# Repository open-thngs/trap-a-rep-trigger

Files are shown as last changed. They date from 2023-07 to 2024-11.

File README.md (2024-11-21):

# Openthing 2 - RepTrap 

The RepTrap is a "motion detector" and camera trigger designed to detect small and/or cold-blooded animals such as frogs, lizards, birds, and other wildlife. It doesn't detect motion directly but instead identifies changes in height within the range of its four Time-of-Flight (ToF) sensors. Any height change within this range triggers a connected camera's shutter.

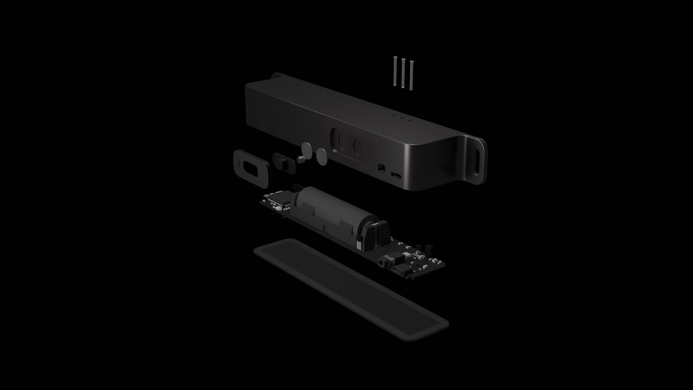
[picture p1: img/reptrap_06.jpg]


## BLE 

The device and software is Bluetooth ready but it is currently missing an App. Here are commands which can be send to configure and change the device:

- Bluetooth Service [`0x7017`]
    - **Status** Characteristic [`0x701C`]
      **Description**: Refelcts the current device status as a string
      **Values**: `running` `calibrating`
    - **Command** Characteristic [`0x7018`]
      **Description**: Accepts specific device commands
      **Values:**
      - `stop`: Stops the BLE Service on the device
      - `calibrate`: Triggers a re-calibration of the device
      - `xtalk`: Triggers an cross-talk and offset calibration of the device (only needed for manufacturing, should not be used)
      - `trigger`: Triggers the camera shutter and focus signal
    - **Config** Characteristic [`701D`]
      **Description**: Using this characteristic you can configure the device (**experimental**). You can send a 3 Byte payload consisting of the type (first byte) and tzhe data(second and third byte). Example `[0xA0, 0x00, 0x00]` Type 0xA0 Signal Threashold with value 0
      **Values**:
        - `0xA0` - Signal Threshold
        - `0xA1` - Sigma Threshold
        - `0xA2` - Time to Measure
        - `0xA3` - Measure Interval

**Note:** The config characteristic is experimental. The limits of the values might not be checked or some value combination might lead to an unresponsive sensor. A re-flash of the firmware might be needed to fix the device. You can read the datasheet of the ToF Sensor to get the details of this values.

**Note:** If you want to power the device permanently via USB-C the BLE Service will be started once you boot the device with USB-C connected. You can send teh command to stop the BLE Service to save energy. 

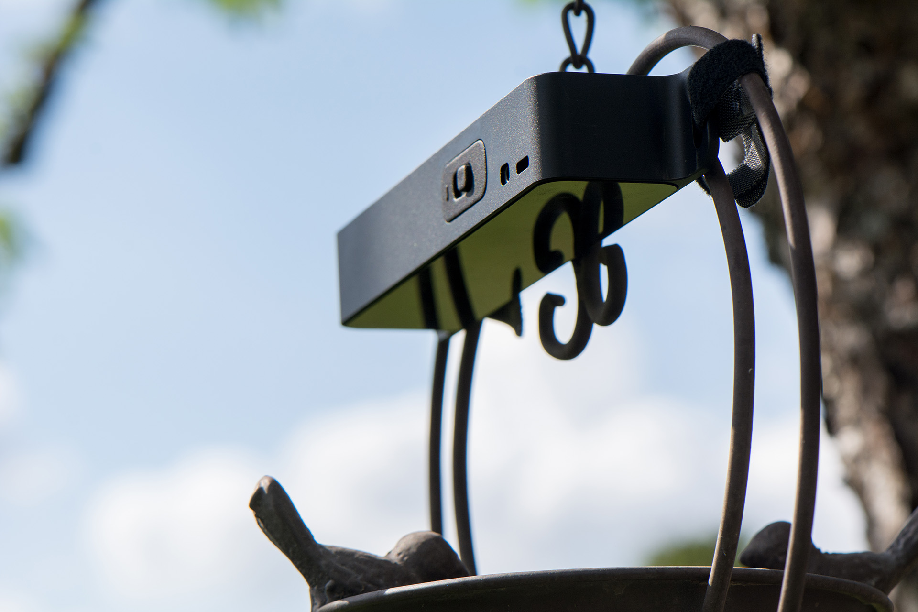
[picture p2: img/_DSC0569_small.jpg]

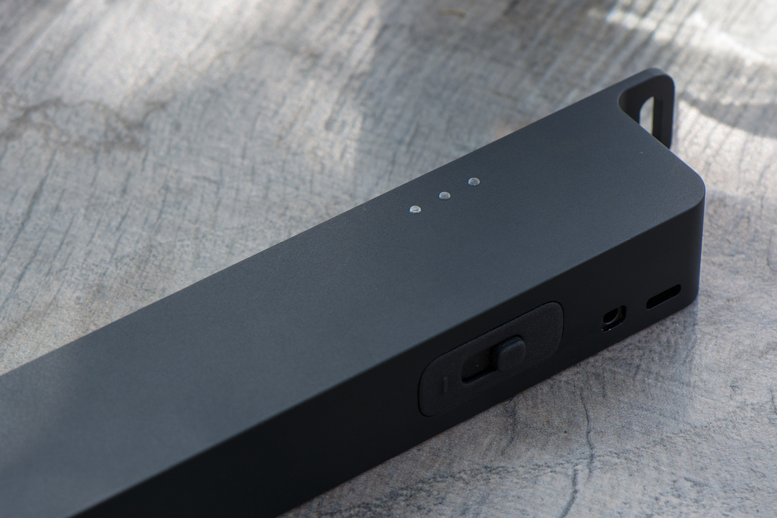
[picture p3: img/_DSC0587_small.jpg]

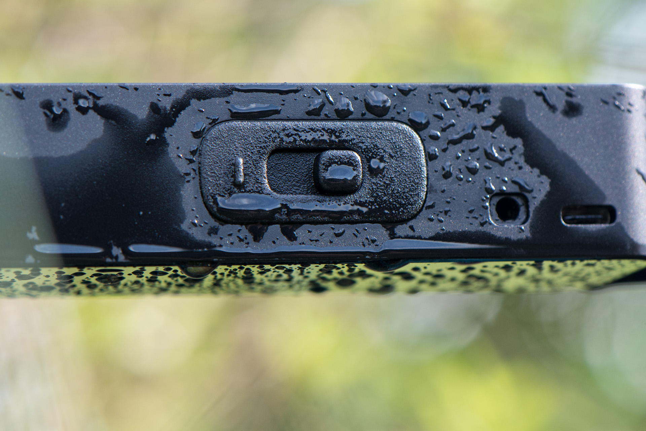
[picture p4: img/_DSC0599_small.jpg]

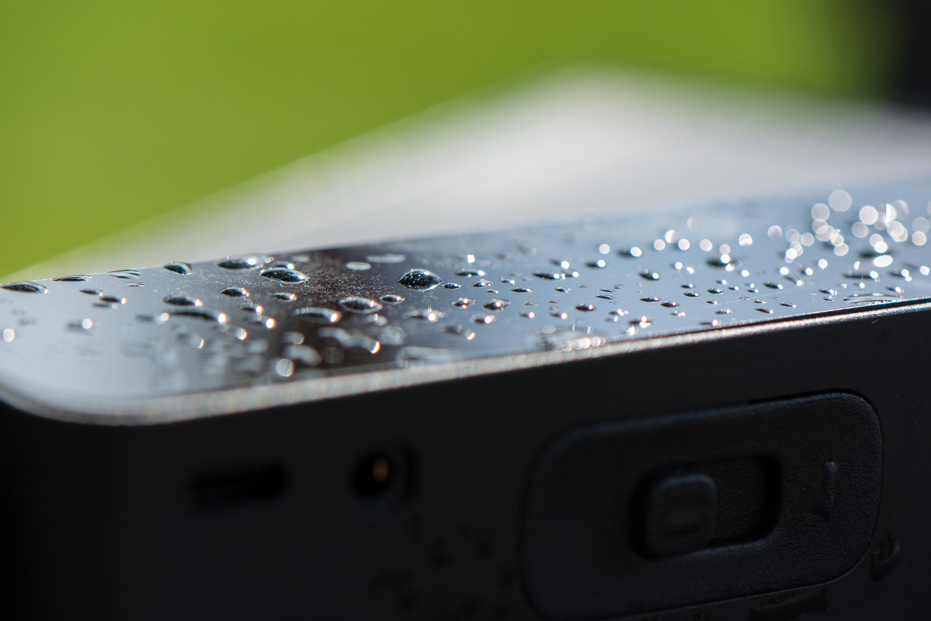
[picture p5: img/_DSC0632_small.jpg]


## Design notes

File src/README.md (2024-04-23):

## Toit usage
flash: `jag flash -p COM19 --chip esp32s3`
install container: `jag container install app -D jag.disabled -D jag.timeout=5m src/main.toit`

## Full Firmware build
compile main app `toit.compile -w komodo.snapshot src/komodo.toit`
install container to envelope: `firmware -e firmware-esp32s3.envelope  container install komodo komodo.snapshot`
flash: `firmware -e firmware-esp32s3.envelope flash -p COM19 --baud 921600 --chip esp32s3`

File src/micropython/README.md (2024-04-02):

If the Sensor is used for the first time it might need calibration (if a cover glas is used)
Make sure to set the Sensor on a 10cm height and place a white paper below it and run 
```
import calibrator
calibrator.calibrate()
```

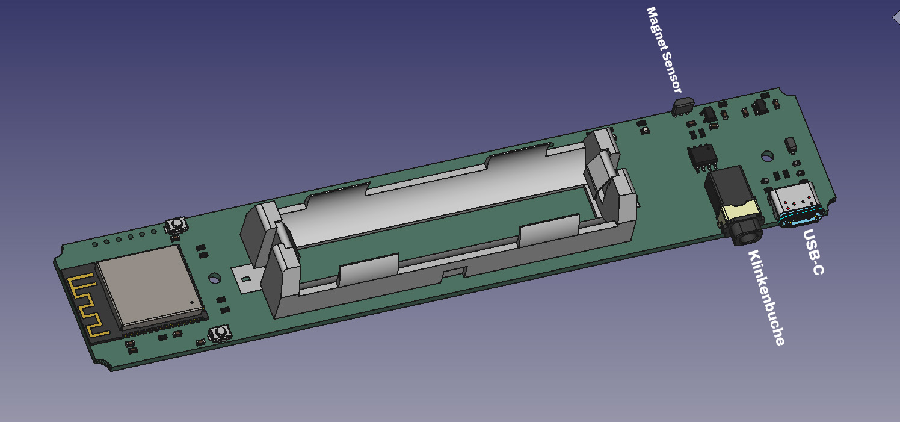
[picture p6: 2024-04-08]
img/3ddescription.jpg

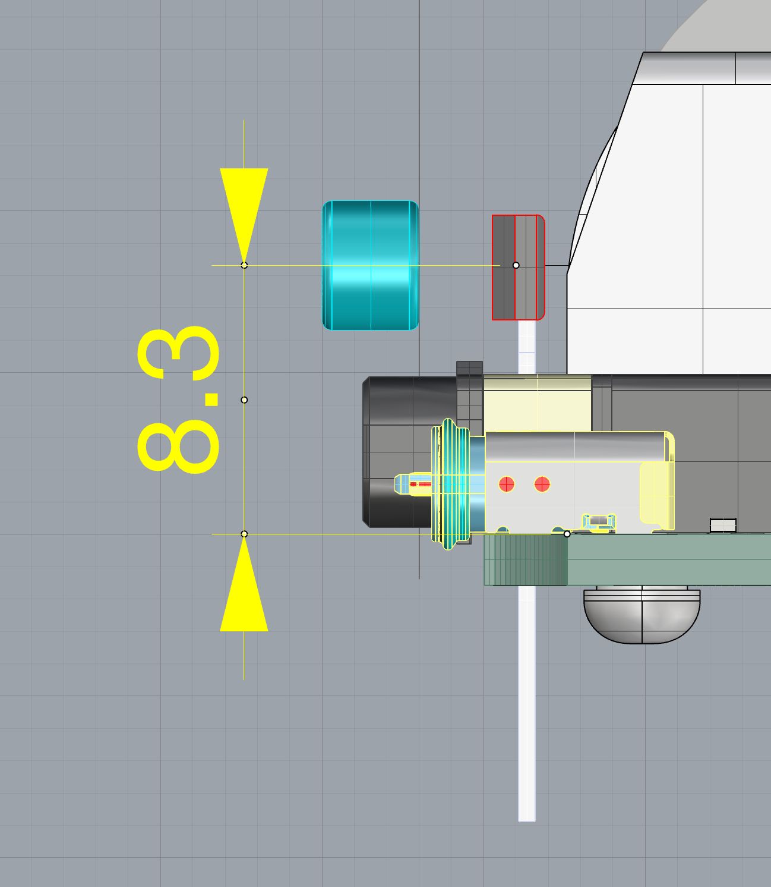
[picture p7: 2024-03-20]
housing/magnet-sensor-height.jpg

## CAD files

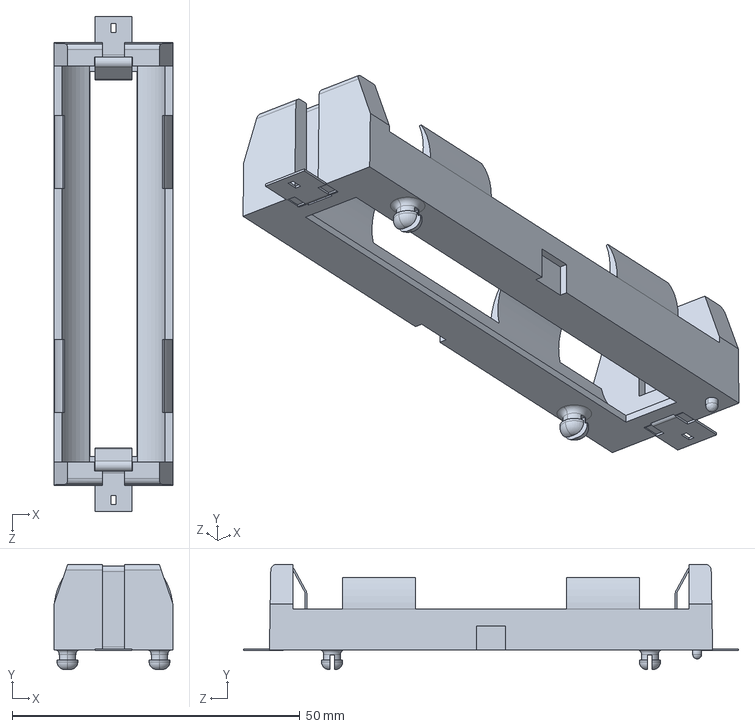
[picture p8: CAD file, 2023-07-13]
pcb/components/1042P/1042P.stp
20.7 x 18.3 x 86.1 mm

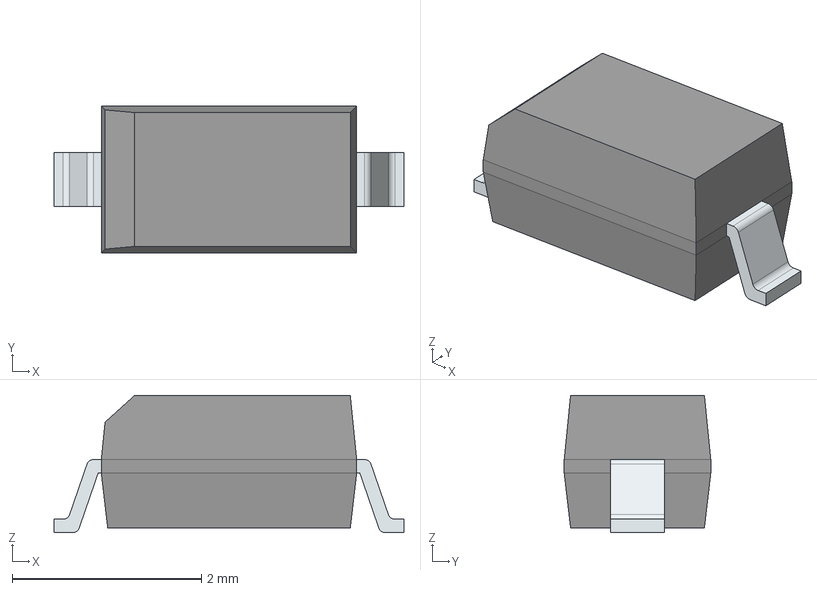
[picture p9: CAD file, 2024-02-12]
pcb/components/1N5819HW-7-F/3D/1N5819HW-7-F.stp
3.70 x 1.55 x 1.45 mm
FilletPinL
FilletPinR

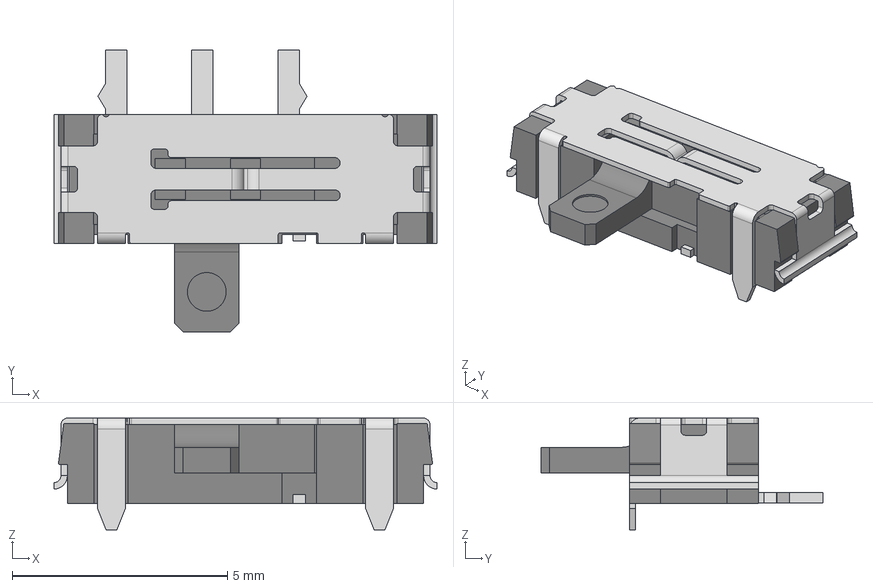
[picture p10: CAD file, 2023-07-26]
pcb/components/450405020524/STP_450405020524 (rev1).stp
8.90 x 6.55 x 2.60 mm
Frame
Cover
Pin 2
Pin 4
Slider 1
Pin 1
Pin 3
Slider
Pin 5

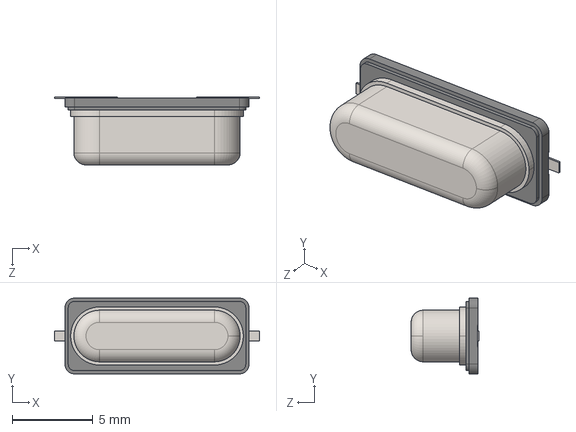
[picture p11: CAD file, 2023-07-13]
pcb/components/ABLS-12.000MHZ-B4-T/3D/ABLS-12.000MHZ-B4-T.stp
12.7 x 4.70 x 4.20 mm

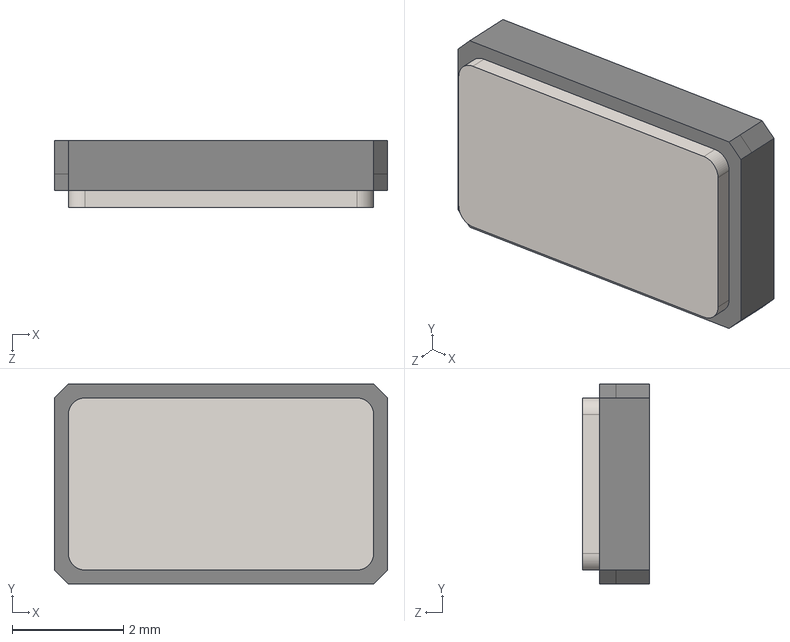
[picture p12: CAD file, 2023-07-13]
pcb/components/ABMM2-12.000MHZ-E2-T/3D/ABMM2-12.000MHZ-E2-T.stp
6.00 x 3.60 x 1.20 mm

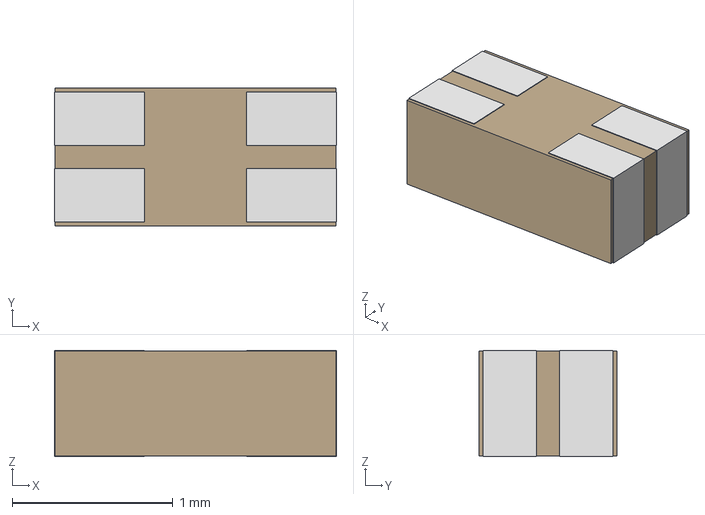
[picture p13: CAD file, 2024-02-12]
pcb/components/APHF1608LSEEQBDZGKC/3D/APHF1608SEEQBDZGKC_KNB.step
1.75 x 0.856 x 0.66 mm

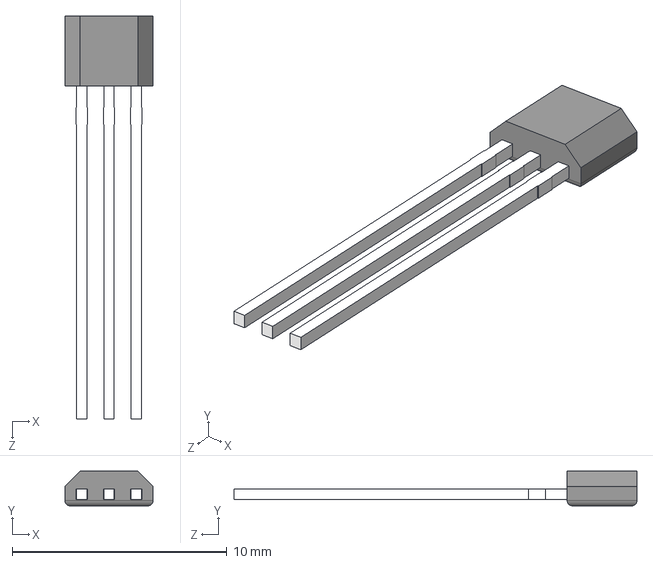
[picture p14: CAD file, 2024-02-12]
pcb/components/DRV5032DULPGM/3D/DRV5032DULPGM.stp
4.10 x 1.62 x 18.8 mm

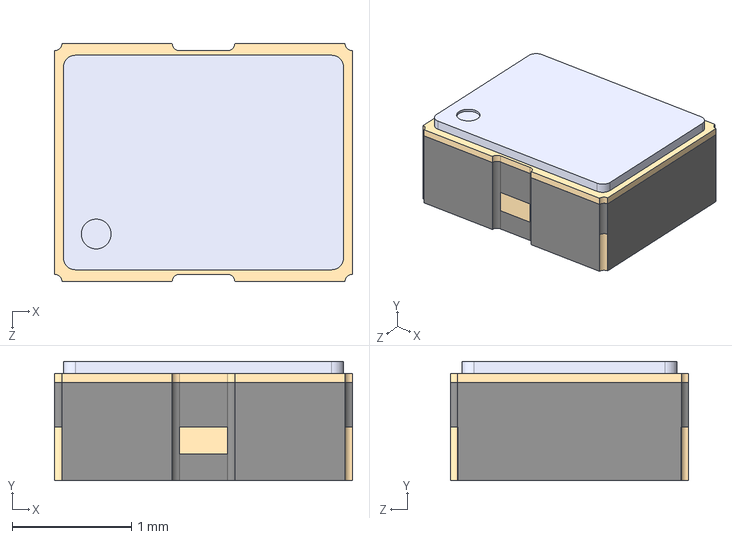
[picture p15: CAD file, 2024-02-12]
pcb/components/ECS-2033-120-BN/ECS-2033-120-BN.STEP
2.50 x 1.00 x 2.00 mm

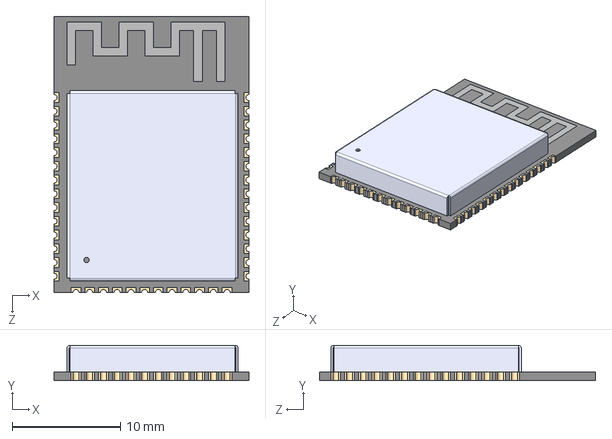
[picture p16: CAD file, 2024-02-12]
pcb/components/ESP32-S3/ESP32-S3-WROOM-1-N8.STEP
18.0 x 3.25 x 25.5 mm

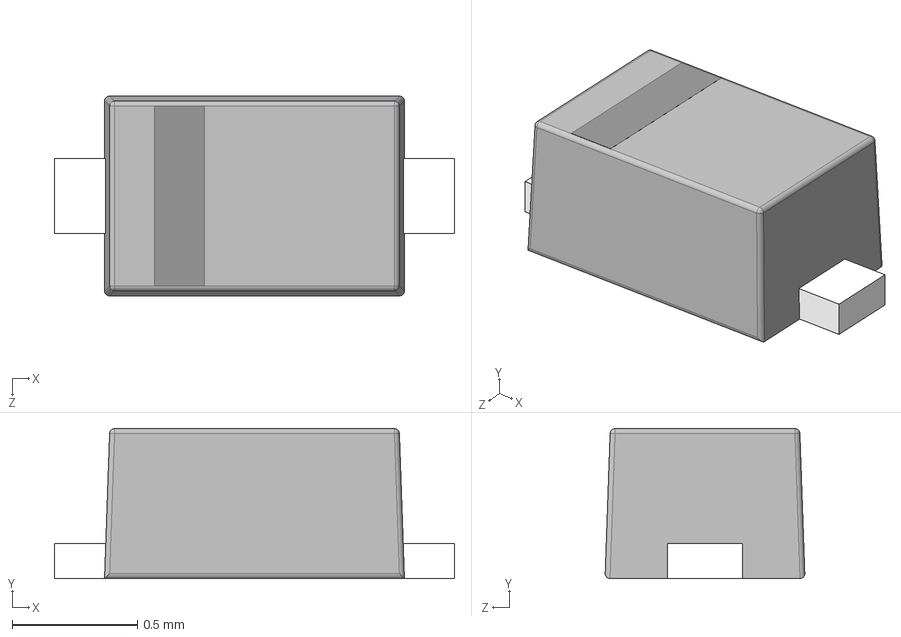
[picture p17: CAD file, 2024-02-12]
pcb/components/LESD5D5.0CT1G/3D/LESD5D5.0CT1G.stp
1.60 x 0.601 x 0.799 mm

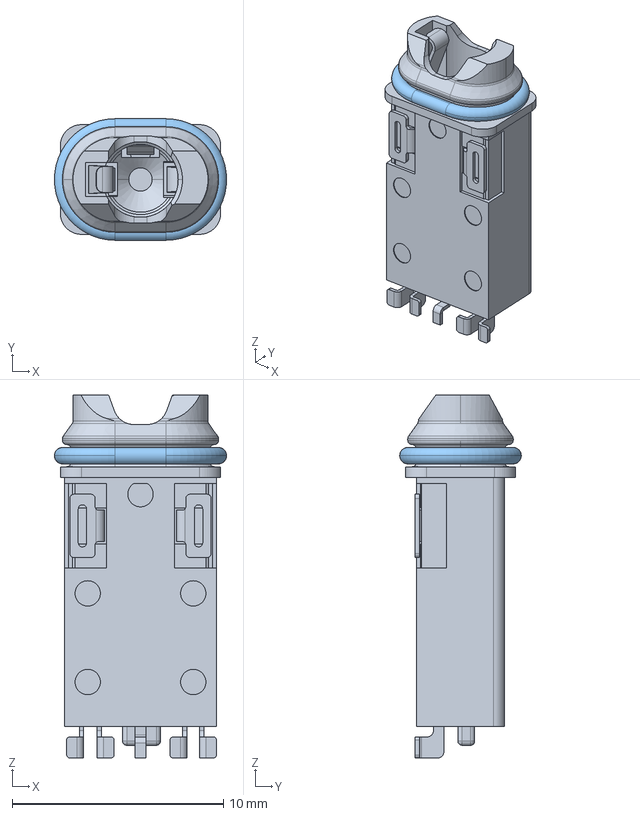
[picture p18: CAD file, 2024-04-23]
pcb/components/PJ-3255A/3D/PJ-3255A.stp
8.16 x 5.76 x 17.2 mm
3255A-
MANIFOLD_SOLID_BREP_21750
MANIFOLD_SOLID_BREP_22076

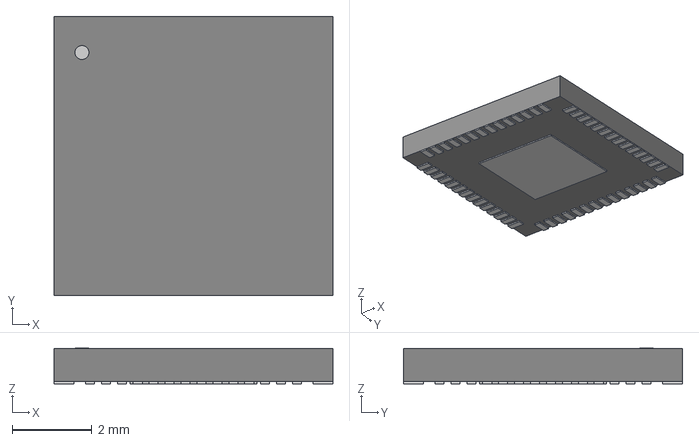
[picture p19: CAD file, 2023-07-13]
pcb/components/RP2040/3D/IC57_RP2040.step
7.01 x 7.01 x 0.892 mm

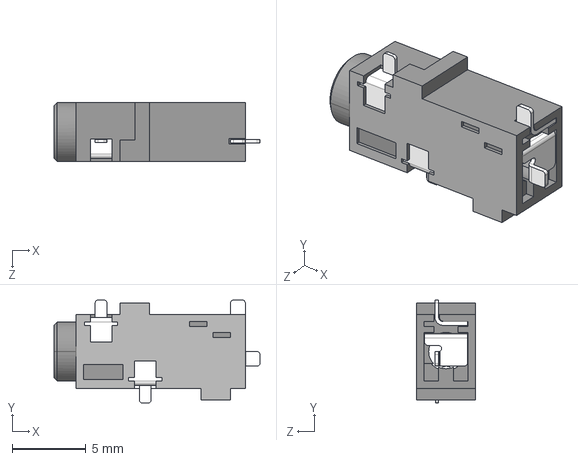
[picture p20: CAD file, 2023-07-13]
pcb/components/SJ-25773B-SMT/CUI_DEVICES_SJ2-25773B-SMT-TR.step
14.0 x 7.00 x 4.00 mm

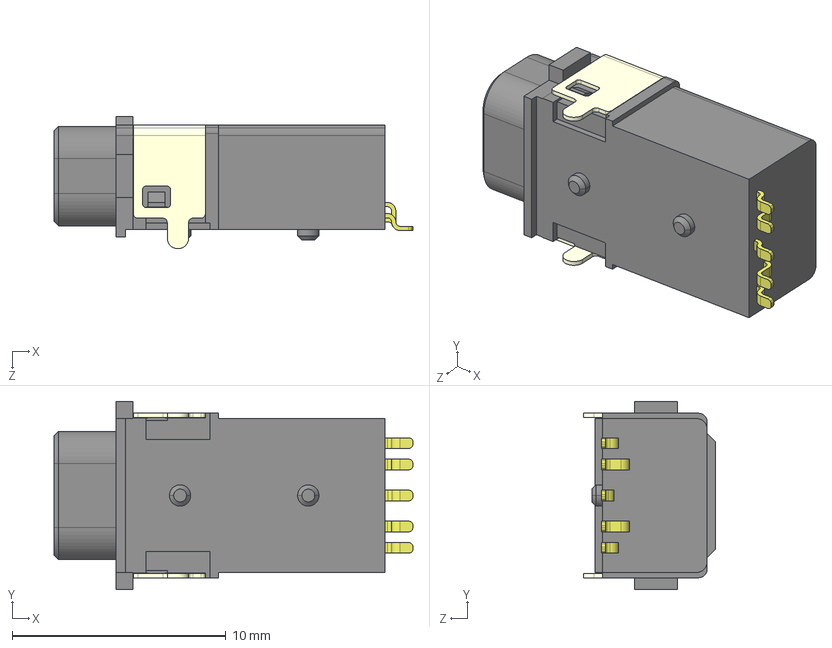
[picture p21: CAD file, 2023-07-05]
pcb/components/SJ-3541AS-SMT-TR-67/CUI_DEVICES_SJ-3541AS-SMT-TR-67.step
16.8 x 8.80 x 6.20 mm

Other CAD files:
pcb/components/SKRKAEE020/SKRKAEE020.stp
pcb/components/USB4105-GF-A/USB4105-GF-A.step
pcb/components/VL53L4CD/3D/VL53L4CDV0DH_1.stp
housing/rep-trap-gehaeuse_240506.stp
housing/240319_Gehaeuse.stp
housing/240319_Schalter.stl
housing/240319_Schalterhalter.stl
housing/240530needles.stl
housing/calibration-station.3mf
housing/glass.stl
pcb/components/124018612112A/12401861.stp
pcb/components/18650.step
pcb/components/APHF1608LSEEQBDZGKC/3D/APHF1608.IGS
pcb/components/APHF1608LSEEQBDZGKC/3D/APHF1608.STEP
pcb/components/APHF1608LSEEQBDZGKC/3D/APHF1608_.STEP
pcb/components/SKRKAEE020/SKRKAE.STEP

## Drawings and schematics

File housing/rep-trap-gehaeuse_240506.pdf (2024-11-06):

192.6

205.3

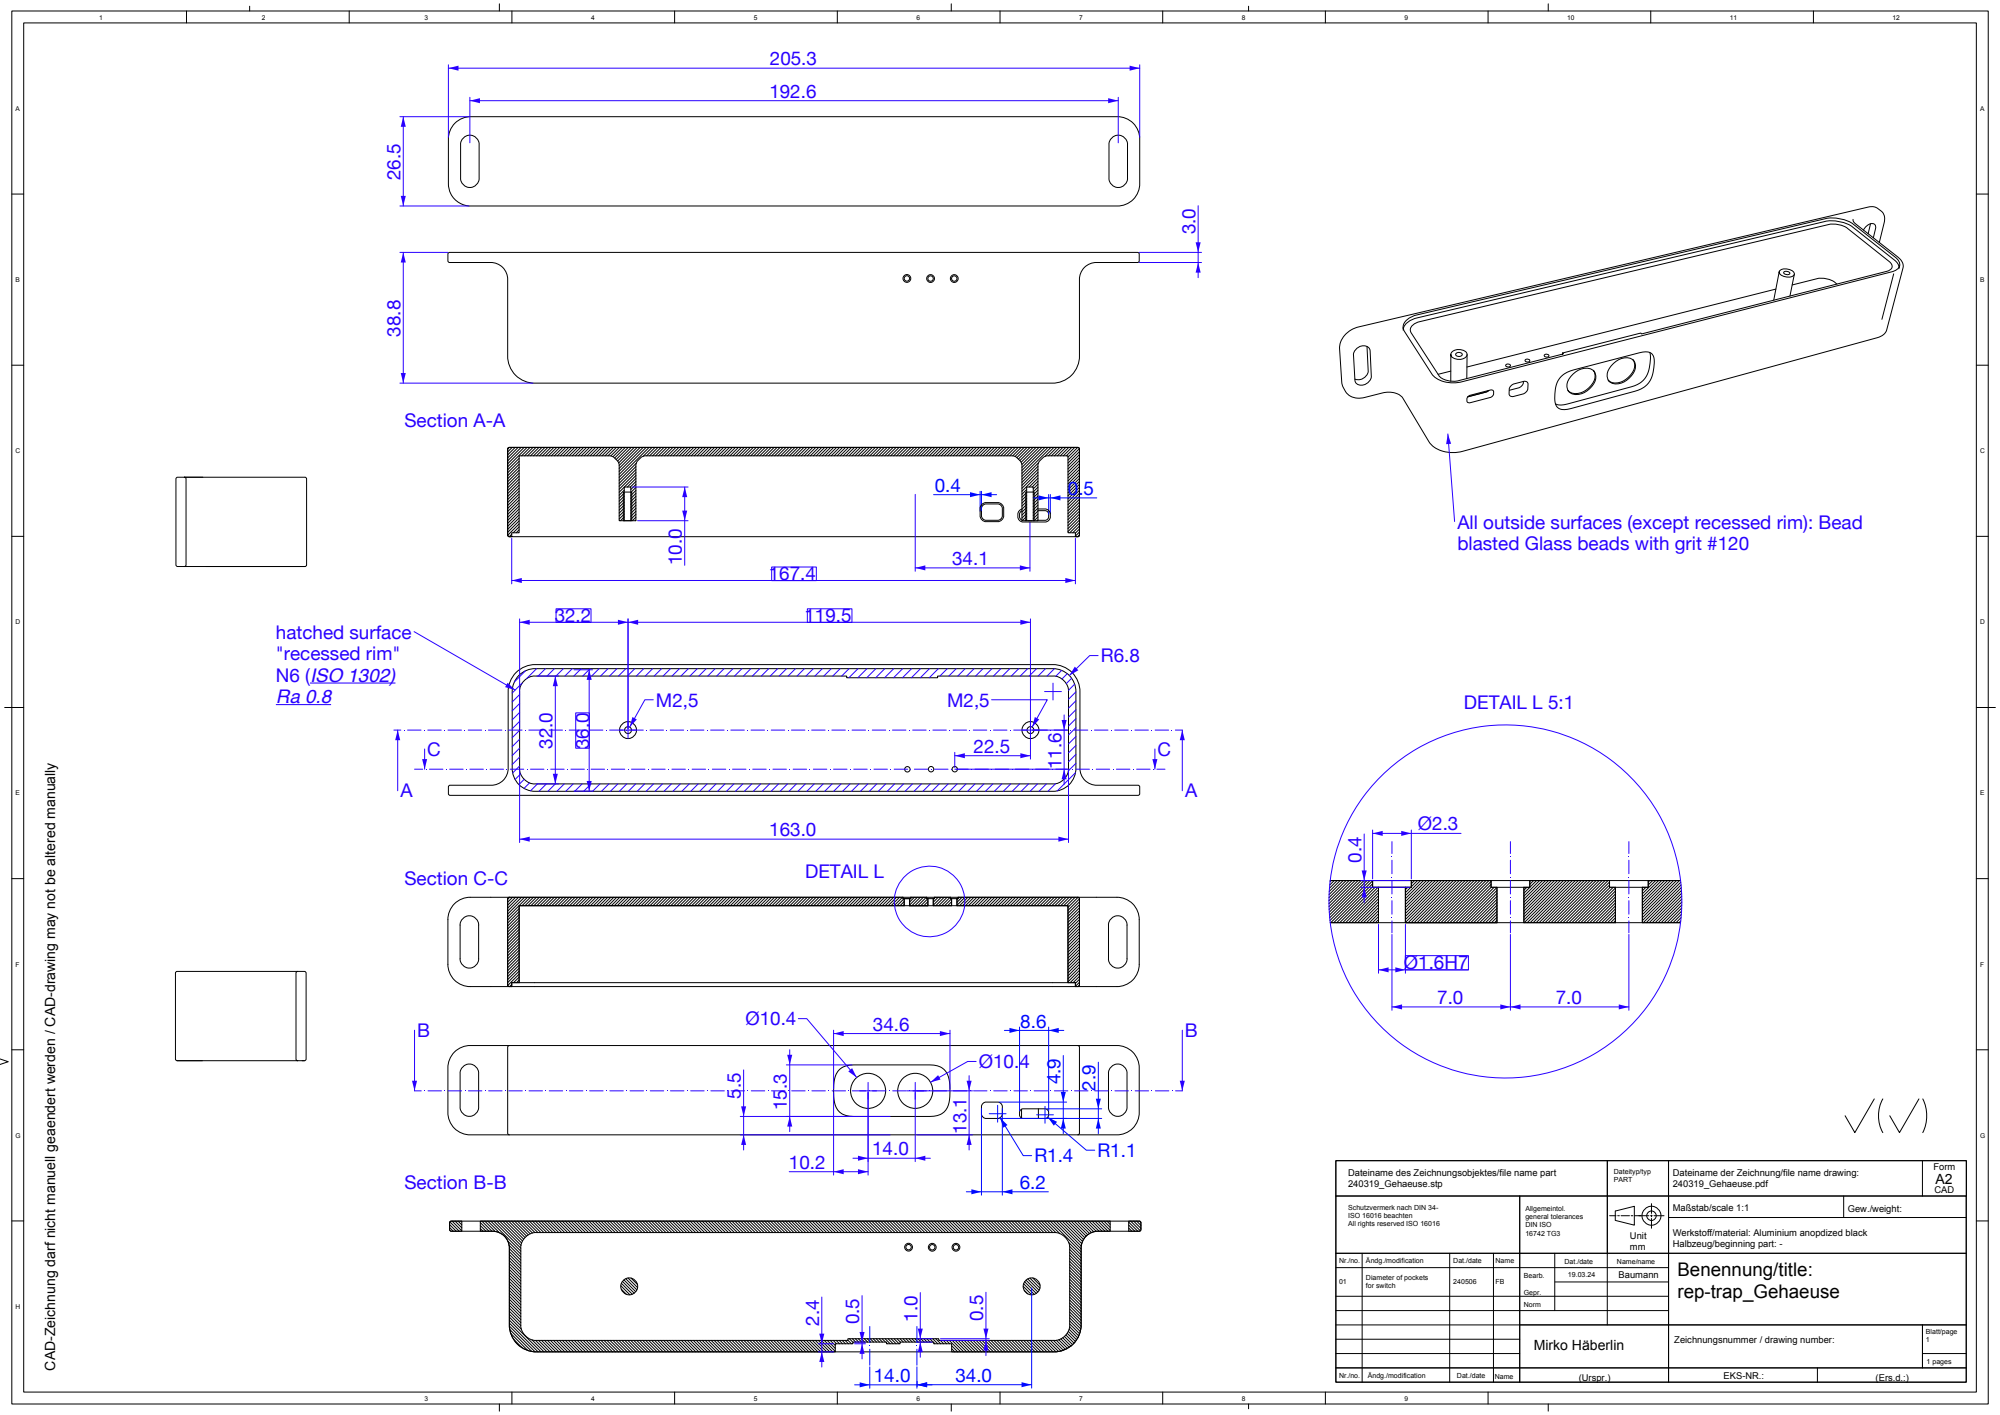
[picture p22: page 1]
Blatt/page 1; Dateityp/typ PART; Bearb.; Gepr.; 1 pages; Ändg./modification; Name; Gew./weight:; Mirko Häberlin; Maßstab/scale 1:1; Dat./date; Norm; Name/name; Allgemeintol. general tolerances DIN ISO 16742 TG3; CAD; Unit mm; FEA; FEDC; Baumann; (Urspr.); EKS-NR.:; (Ers.d.:); Section B-B; hatched surface "recessed rim" N6 (ISO 1302) Ra 0.8; Section A-A; Section C-C; DETAIL L 5:1; DETAIL L

All outside surfaces (except recessed rim): Bead
blasted Glass beads with grit #120

CAD-Zeichnung darf nicht manuell geaendert werden / CAD-drawing may not be altered manually

Form Dateiname des Zeichnungsobjektes/file name part
240319_Gehaeuse.stp

Dateiname der Zeichnung/file name drawing:
240319_Gehaeuse.pdf

Schutzvermerk nach DIN 34-
ISO 16016 beachten
All rights reserved ISO 16016

Werkstoff/material: Aluminium anopdized black
Halbzeug/beginning part: -
Benennung/title:
rep-trap_Gehaeuse

Diameter of pockets
for switch

Zeichnungsnummer / drawing number:

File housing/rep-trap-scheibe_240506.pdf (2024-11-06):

R6.6

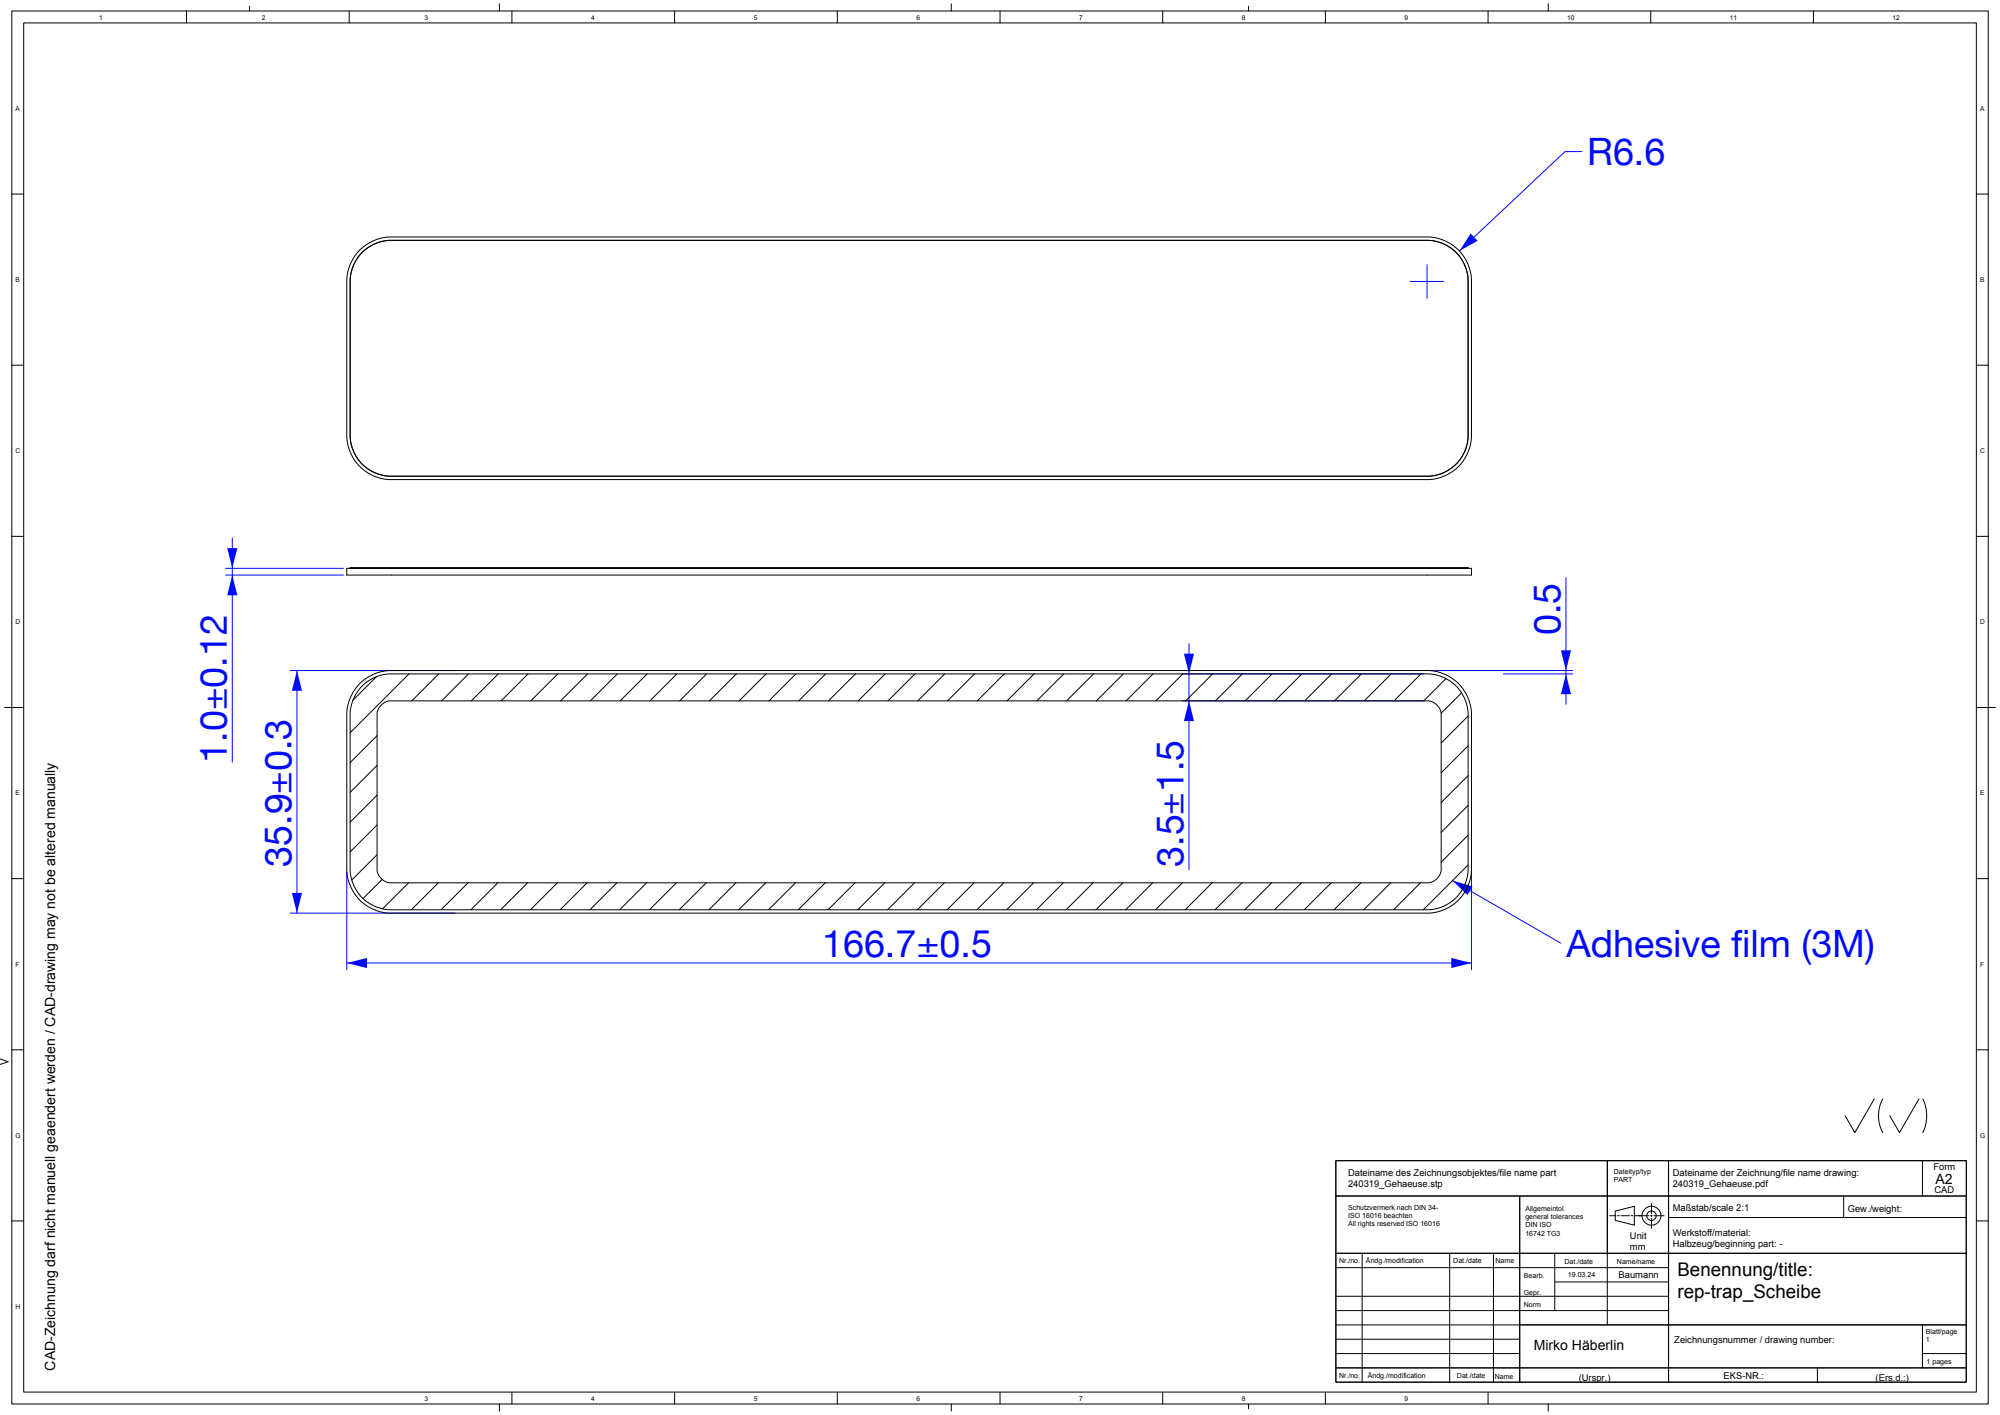
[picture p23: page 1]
Baumann; Mirko Häberlin; GBH; Allgemeintol. general tolerances DIN ISO 16742 TG3; DCB; 1 pages; Norm; Form; Ändg./modification; (Ers.d.:); Gew./weight:; Blatt/page 1; Dateityp/typ PART; Name/name; Gepr.; Dat./date; CAD; Bearb.; Name; Unit mm; Maßstab/scale 2:1; Adhesive film (3M)

CAD-Zeichnung darf nicht manuell geaendert werden / CAD-drawing may not be altered manually

Dateiname des Zeichnungsobjektes/file name part
240319_Gehaeuse.stp

Dateiname der Zeichnung/file name drawing:
240319_Gehaeuse.pdf

Schutzvermerk nach DIN 34-
ISO 16016 beachten
All rights reserved ISO 16016

Werkstoff/material:
Halbzeug/beginning part: -
Benennung/title:
rep-trap_Scheibe

Zeichnungsnummer / drawing number:

EKS-NR.: (Urspr.)

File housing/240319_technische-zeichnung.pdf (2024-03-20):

# All rights reserved ISO 16016 9

192.6

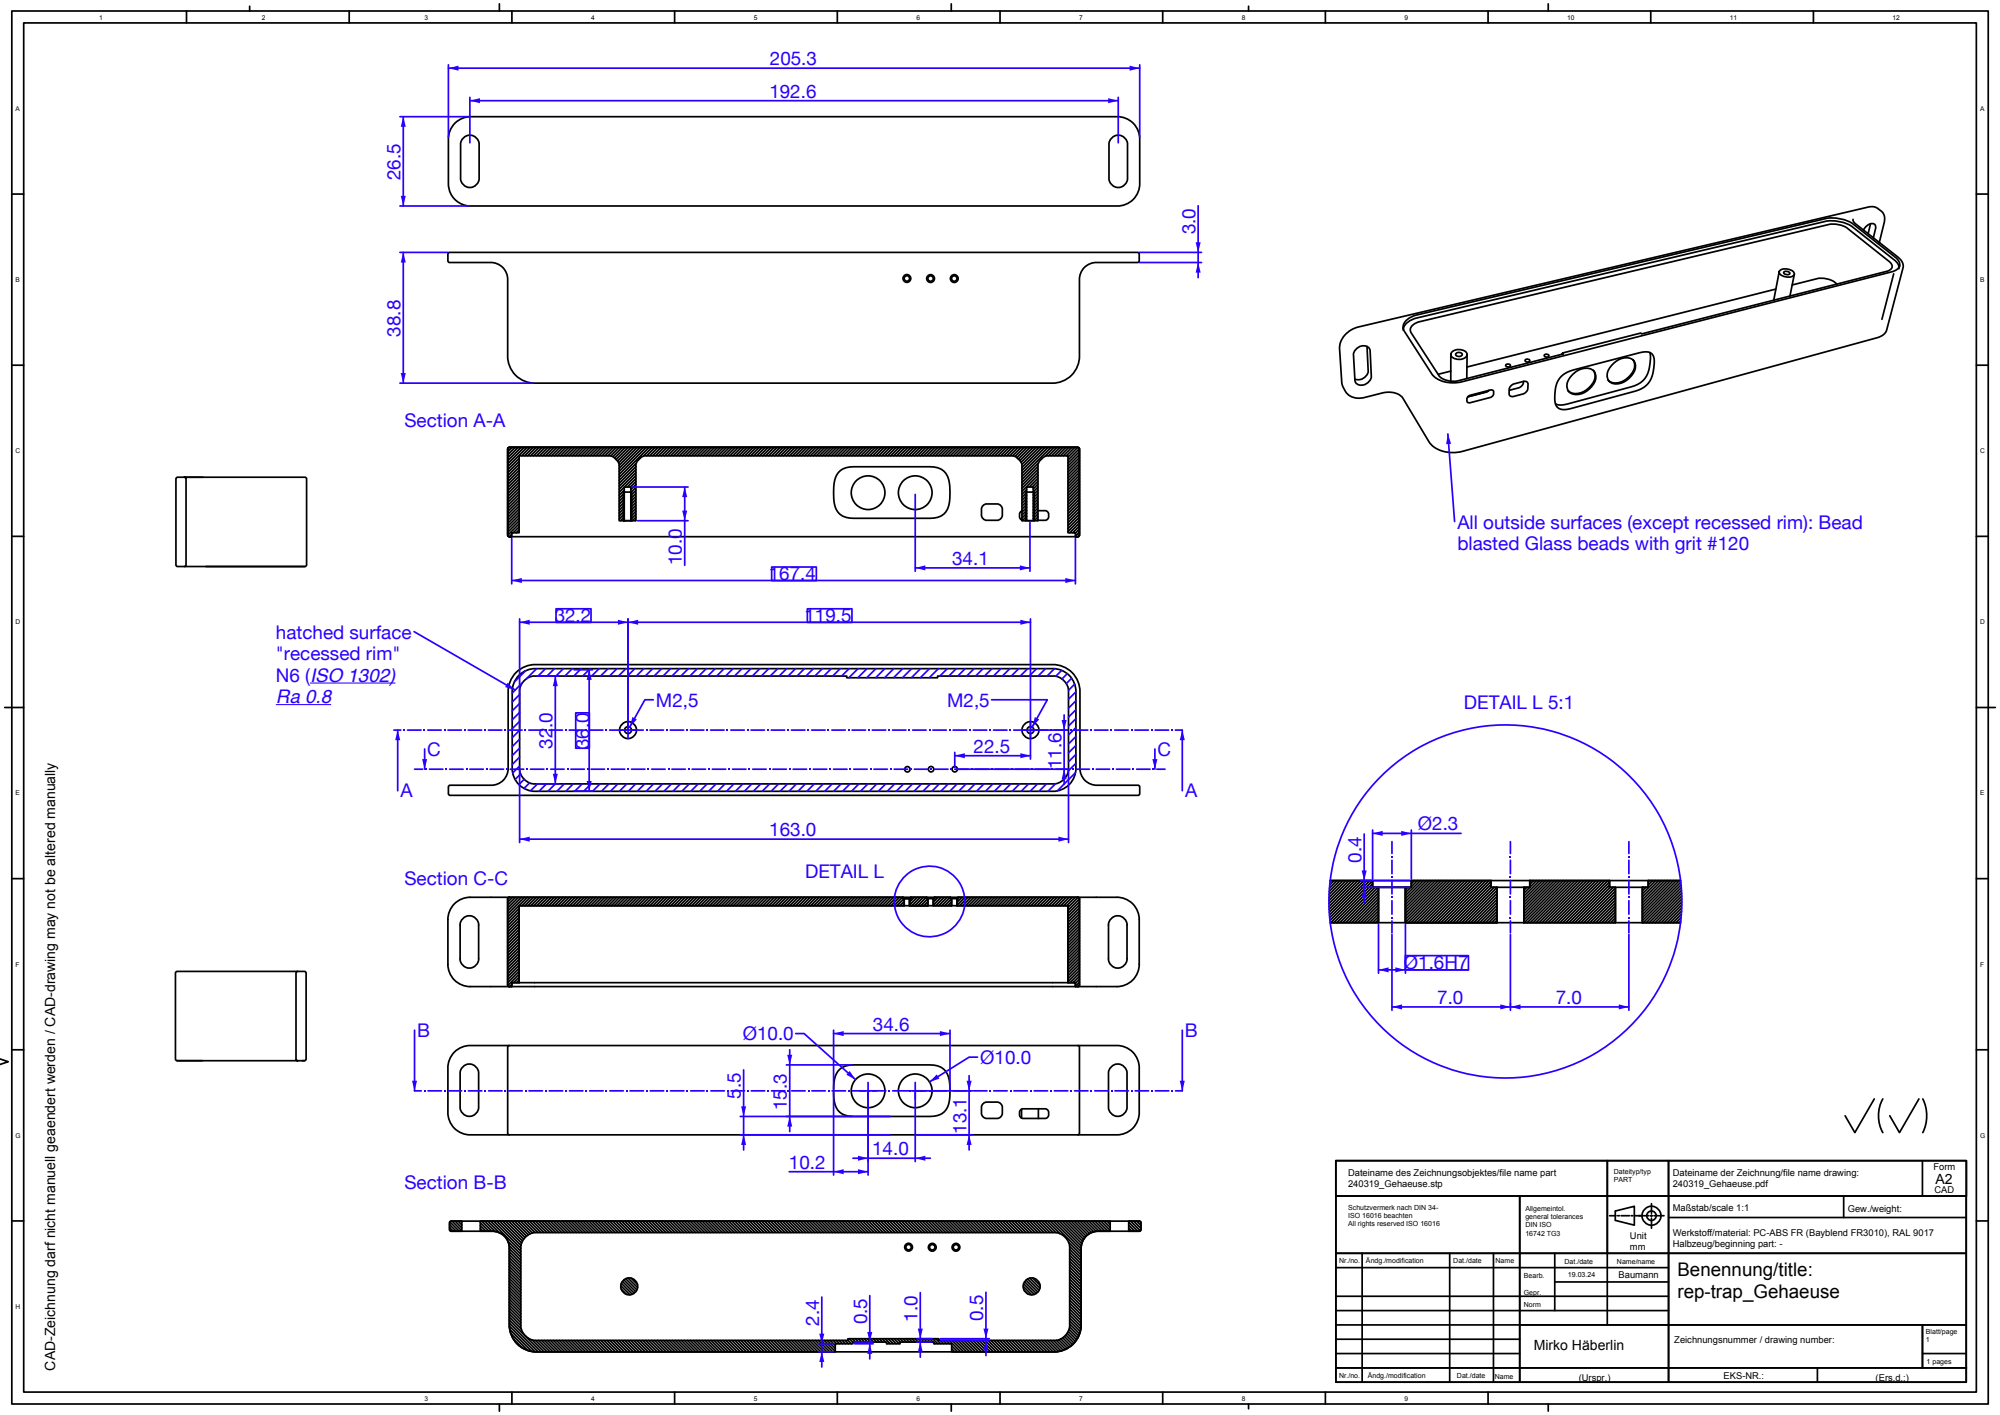
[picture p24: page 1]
Baumann; CAD; Dat./date; Name/name; Dateityp/typ PART; Form A2; Mirko Häberlin; Maßstab/scale 1:1; Gepr.; Gew./weight:; Name; 1 pages; Ändg./modification; Norm; Bearb.; Allgemeintol. general tolerances DIN ISO 16742 TG3; Blatt/page 1; Unit mm; (Ers.d.:); BCDFG; HFEDB; DETAIL L; DETAIL L 5:1; hatched surface "recessed rim" N6 (ISO 1302) Ra 0.8; Section A-A; Section B-B; Section C-C

All outside surfaces (except recessed rim): Bead
blasted Glass beads with grit #120

CAD-Zeichnung darf nicht manuell geaendert werden / CAD-drawing may not be altered manually

Dateiname des Zeichnungsobjektes/file name part
240319_Gehaeuse.stp

Dateiname der Zeichnung/file name drawing:
240319_Gehaeuse.pdf

Schutzvermerk nach DIN 34-
ISO 16016 beachten

Werkstoff/material: PC-ABS FR (Bayblend FR3010), RAL 9017
Halbzeug/beginning part: -
Benennung/title:
rep-trap_Gehaeuse

Zeichnungsnummer / drawing number:

EKS-NR.: (Urspr.)

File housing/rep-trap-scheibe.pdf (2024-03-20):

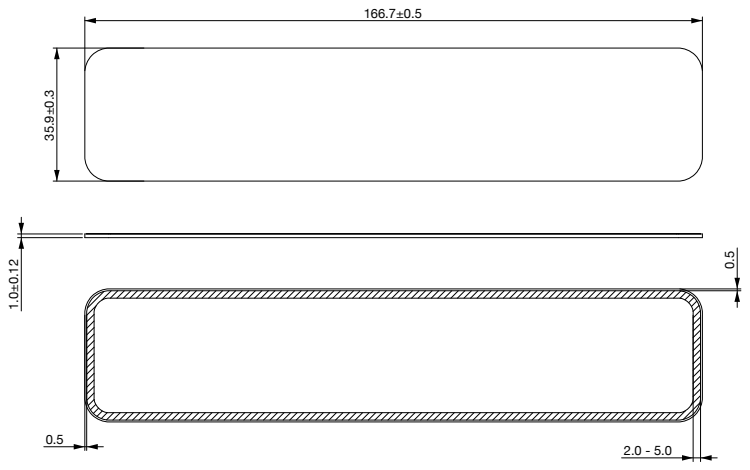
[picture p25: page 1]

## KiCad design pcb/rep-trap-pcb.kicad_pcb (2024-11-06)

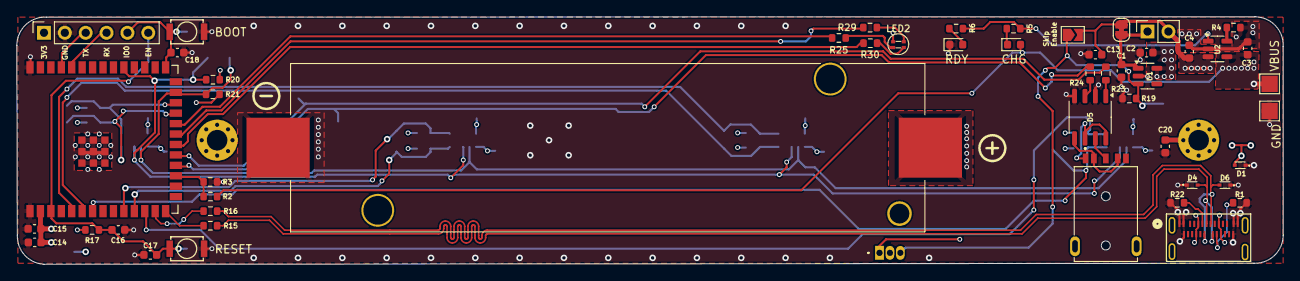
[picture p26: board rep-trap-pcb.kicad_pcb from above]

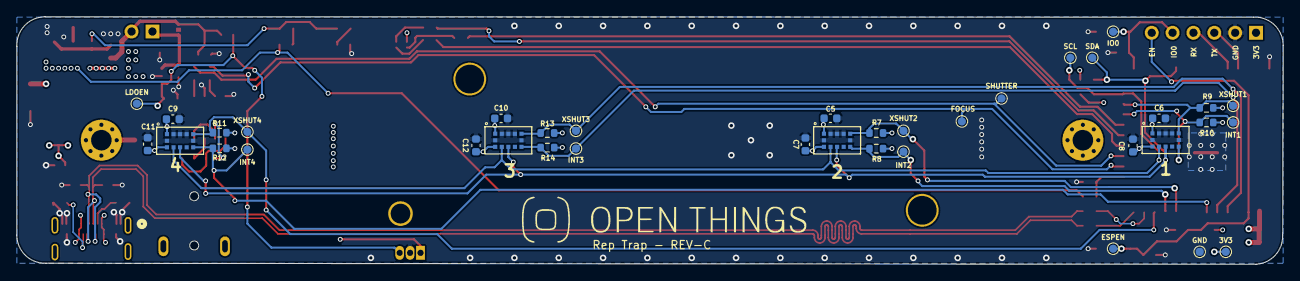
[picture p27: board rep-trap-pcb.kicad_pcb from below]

Board: 4 copper layers, 154.2 x 30.1 mm, 91 parts (38 on the bottom side), 45 nets.

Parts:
BT1: BH-18650-B1BA002; 1042P
C1, C2, C16: 1µF; C_0603_1608Metric
C3, C4, C14: 10µF; C_0603_1608Metric
C5, C6, C9, C10: 4.7µF; C_0603_1608Metric
C7, C8, C11, C12, C13, C15, C20: 0.1µF; C_0603_1608Metric
C17, C18: 0.1µF/DNP; C_0603_1608Metric
D1, D4, D6: LESD5D5.0CT1G; LESD5D50CT1G
D2: LED_RED; LED_0603_1608Metric
D3: LED_GREEN; LED_0603_1608Metric
D5: ILD213T; SO-8_3.9x4.9mm_P1.27mm
G1: LOGO
H1, H2: MountingHole_Pad; MountingHole_2.5mm_Pad_Via
IC1: DRV5032FBLPG; DRV5032DULPGM
J3: PJ-3254A-SMT; CUI_SJ-3541AS-SMT-TR-67
J4: VBUS; TestPoint_Pad_2.0x2.0mm
J5: Conn_01x02_Pin; PinSocket_1x02_P2.54mm_Vertical
J7: GND; TestPoint_Pad_2.0x2.0mm
J8: 124018612112A; CONN_124018612112A_AMP
J9: DNP; PinSocket_1x06_P2.54mm_Vertical
JP1: SolderJumper_2_Open; SolderJumper-2_P1.3mm_Open_TrianglePad1.0x1.5mm
JP2: Jumper_2_Bridged; SolderJumper-2_P1.3mm_Bridged_RoundedPad1.0x1.5mm
LED2: APHF1608LSEEQBDZGKC
R1, R22: 5k1; R_0603_1608Metric
R2: 4.7k; R_0603_1608Metric
R3, R7, R8, R9, R10, R11, R12, R13, R14, R17: 10k; R_0603_1608Metric
R4: 2k; R_0603_1608Metric
R5, R6: 1k; R_0603_1608Metric
R15, R16: 0R; R_0603_1608Metric
R19: 10k/DNP; R_0603_1608Metric
R20, R21, R29: 2.2k; R_0603_1608Metric
R23, R24: 47R; R_0603_1608Metric
R25: 1k2; R_0603_1608Metric
R30: 390R; R_0603_1608Metric
SW1, SW2: SKRKAEE020
TP1: TB_SDA; TestPoint_Pad_D1.0mm
TP2: TP_SCL; TestPoint_Pad_D1.0mm
TP3, TP17: TP_3V3; TestPoint_Pad_D1.0mm
TP4: TP_XSHUT_1; TestPoint_Pad_D1.0mm
TP5: TP_INT_1; TestPoint_Pad_D1.0mm
TP6: TP_XSHUT_2; TestPoint_Pad_D1.0mm
TP7: TP_INT_2; TestPoint_Pad_D1.0mm
TP8: TP_XSHUT_4; TestPoint_Pad_D1.0mm
TP9: TP_INT_4; TestPoint_Pad_D1.0mm
TP10: TP_XSHUT_3; TestPoint_Pad_D1.0mm
TP11: TP_INT_3; TestPoint_Pad_D1.0mm
TP12: TP_EN_ESP; TestPoint_Pad_D1.0mm
TP13: TP_GPIO0; TestPoint_Pad_D1.0mm
TP14: TP_LDO_EN; TestPoint_Pad_D1.0mm
TP15: TP_SHUTTER; TestPoint_Pad_D1.0mm
TP16: TP_FOCUS; TestPoint_Pad_D1.0mm
U1: AP2112K-3.3; SOT-23-5
U2: MCP73831/OT; SOT-23-5
U3, U4, U5, U6: VL53L4CDV0DH/1; LGA12_STM
U7: ESP32-S3-WROOM-1

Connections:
+3.3V: C2.1, C5.1, C6.1, C7.1, C8.1, C9.1, C10.1, C11.1, C12.1, C14.1, C15.1, J9.1, LED2.1 (A), R7.2, R8.2, R9.2, R10.2, R11.2, R12.2, R13.2, R14.2, R17.2, R20.2, R21.2, TP3.1, U1.5 (VOUT), U3.1 (AVDDVCSEL), U3.11 (AVDD), U4.1 (AVDDVCSEL), U4.11 (AVDD), U5.1 (AVDDVCSEL), U5.11 (AVDD), U6.1 (AVDDVCSEL), U6.11 (AVDD), U7.2 (3V3)
+BATT: BT1.1 (+), C4.1, C13.1, IC1.1 (VCC), J5.2, JP1.2 (B), JP2.2 (B), U2.3 (V_{BAT})
/main/AUTOFOCUS: R24.1, TP16.1, U7.18 (GPIO10/TOUCH10/ADC1_CH9/FSPICS0/FSPIIO4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)
/main/ENABLE: IC1.3 (OUT2), JP1.1 (A), R19.2, TP14.1, U1.3 (EN)
/main/END: D5.6 (COLLECTOR_1), D5.8 (COLLECTOR_2), J3.1
/main/MCU/EN: C16.1, C17.1, J9.6, R17.1, SW2.2, TP12.1, U7.3 (EN)
/main/MCU/GPIO_0: C18.1, J9.5, SW1.2, TP13.1, U7.27 (GPIO0/BOOT)
/main/MCU/LED_B: R30.1, U7.20 (GPIO12/TOUCH12/ADC2_CH1/FSPICLK/FSPIIO6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)
/main/MCU/LED_G: R29.1, U7.21 (GPIO13/TOUCH13/ADC2_CH2/FSPIQ/FSPIIO7/S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)
/main/MCU/LED_R: R25.2, U7.22 (GPIO14/TOUCH14/ADC2_CH3/FSPIWP/FSPIDQS/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)
/main/MCU/SCL: R21.1, TP2.1, U3.10 (SCL), U4.10 (SCL), U5.10 (SCL), U6.10 (SCL), U7.25 (GPIO48/SPICLK_N/SUBSPICLK_N_DIFF)
/main/MCU/SDA: R20.1, TP1.1, U3.9 (SDA), U4.9 (SDA), U5.9 (SDA), U6.9 (SDA), U7.31 (GPIO38/FSPIWP/SUBSPIWP)
/main/MCU/U0RXD: J9.4, U7.36 (U0RXD/GPIO44/CLK_OUT2)
/main/MCU/U0TXD: J9.3, U7.37 (U0TXD/GPIO43/CLK_OUT1)
/main/MCU/USB_DM: R16.1, U7.13 (GPIO19/U1RTS/ADC2_CH8/CLK_OUT2/USB_D-)
/main/MCU/USB_DP: R15.1, U7.14 (GPIO20/U1CTS/ADC2_CH9/CLK_OUT1/USB_D+)
/main/MCU/~INT_VL53_1: R10.1, TP5.1, U4.7 (GPIO1), U7.23 (GPIO21)
/main/MCU/~INT_VL53_2: R8.1, TP7.1, U3.7 (GPIO1), U7.11 (GPIO18/U1RXD/ADC2_CH7/CLK_OUT3)
/main/MCU/~INT_VL53_3: R14.1, TP11.1, U6.7 (GPIO1), U7.6 (GPIO6/TOUCH6/ADC1_CH5)
/main/MCU/~INT_VL53_4: R12.1, TP9.1, U5.7 (GPIO1), U7.7 (GPIO7/TOUCH7/ADC1_CH6)
/main/MCU/~XSHUT_VL53_1: R9.1, TP4.1, U4.5 (XSHUT), U7.24 (GPIO47/SPICLK_P/SUBSPICLK_P_DIFF)
/main/MCU/~XSHUT_VL53_2: R7.1, TP6.1, U3.5 (XSHUT), U7.10 (GPIO17/U1TXD/ADC2_CH6)
/main/MCU/~XSHUT_VL53_3: R13.1, TP10.1, U6.5 (XSHUT), U7.5 (GPIO5/TOUCH5/ADC1_CH4)
/main/MCU/~XSHUT_VL53_4: R11.1, TP8.1, U5.5 (XSHUT), U7.12 (GPIO8/TOUCH8/ADC1_CH7/SUBSPICS1)
/main/PSU and charging/STAT: R5.1, R6.1, U2.1 (STAT)
/main/PSU and charging/VIN: C1.1, J5.1, JP2.1 (A), U1.1 (VIN)
/main/RING: D5.7 (EMITTER_2), J3.3
/main/SHUTTER: R23.1, TP15.1, U7.19 (GPIO11/TOUCH11/ADC2_CH0/FSPID/FSPIIO5/S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)
/main/TIP: D5.5 (EMITTER_1), J3.2, J3.5
/main/USB_D+: D4.2 (A2), J8.A6 (D1+), J8.B6 (D2+), R15.2
/main/USB_D-: D6.2 (A2), J8.A7 (D1-), J8.B7 (D2-), R16.2
/main/VBUS_DETECT: R2.2, R3.1, U7.17 (GPIO9/TOUCH9/ADC1_CH8/FSPIHD/SUBSPIHD)
GND: BT1.2 (-), C1.2, C2.2, C3.2, C4.2, C5.2, C6.2, C7.2, C8.2, C9.2, C10.2, C11.2, C12.2, C13.2, C14.2, C15.2, C16.2, C17.2, C18.2, C20.2, D1.1 (A1), D3.1 (K), D4.1 (A1), D5.2 (CATHODE_1), D5.4 (CATHODE_2), D6.1 (A1), IC1.2 (GND), J7.1, J8.25 (GND), J8.26 (GND), J8.A1 (GND_A), J8.A12 (GND_A), J8.B1 (GND_B), J8.B12 (GND_B), J9.2, R1.1, R3.2, R4.2, R19.1, R22.1, SW1.1, SW2.1, TP17.1, U1.2 (GND), U2.2 (V_{SS}), U3.2 (AVSSVCSEL), U3.3 (GND), U3.4 (GN2), U3.6 (GND3), U3.12 (GND4), U4.2 (AVSSVCSEL), U4.3 (GND), U4.4 (GN2), U4.6 (GND3), U4.12 (GND4), U5.2 (AVSSVCSEL), U5.3 (GND), U5.4 (GN2), U5.6 (GND3), U5.12 (GND4), U6.2 (AVSSVCSEL), U6.3 (GND), U6.4 (GN2), U6.6 (GND3), U6.12 (GND4), U7.1 (GND), U7.40 (GND), U7.41 (GND)
unnamed: C20.1, H1.1
unnamed: D2.1 (K), R5.2
unnamed: D3.2 (A), R6.2
unnamed: D5.1 (ANODE_1), R23.2
unnamed: D5.3 (ANODE_2), R24.2
unnamed: J8.A5 (CC1), R22.2
unnamed: J8.B5 (CC2), R1.2
unnamed: LED2.3 (B), R30.2
unnamed: LED2.4 (G), R29.2
unnamed: LED2.2 (R), R25.1
unnamed: R4.1, U2.5 (PROG)
VBUS: C3.1, D1.2 (A2), D2.2 (A), J4.1, J8.A4 (VBUS_A), J8.A9 (VBUS_A), J8.B4 (VBUS_B), J8.B9 (VBUS_B), R2.1, U2.4 (V_{DD})

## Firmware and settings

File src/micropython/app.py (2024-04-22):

from machine import I2C, Pin
import machine
import micropython
from micropython import const
import time
import vl53l4cd
import statistics
import sensorcfg
from .rgbled import RGBLED
import esp32
from machine import Pin, lightsleep, wake_reason, idle

TEMPERATURE_CONVERSION_FACTOR = 3.3 / (65535)
TEMPERATURE_OFFSET = const(0.706)

TIME_TO_MEASURE = const(80)
MEASURE_FREQUENCY = const(100)

VL53_ADDR_1 = const(42)
VL53_XSHUNT_1 = const(47)     
VL53_INT_1 = const(21)

VL53_ADDR_2 = const(43)
VL53_XSHUNT_2 = const(17)     
VL53_INT_2 = const(18)

VL53_ADDR_3 = const(44)
VL53_XSHUNT_3 = const(5)     
VL53_INT_3 = const(6)

VL53_ADDR_4 = const(45)
VL53_XSHUNT_4 = const(8)    
VL53_INT_4 = const(7)

start_delay = 5
for i in range(start_delay):
    print("Start in {}s".format(start_delay-i))
    time.sleep(1)
print ("Starting...")

print("Current ESP32 frequency: {} MHz".format(machine.freq() / 1000000))
# machine.freq(62500000)
# print("New RP2040 frequency: {} MHz".format(machine.freq() / 1000000))

debugging = False
last_temperature = 0

shutter = Pin(11, Pin.OUT, Pin.PULL_DOWN)
focus = Pin(10, Pin.OUT, Pin.PULL_DOWN)
led = RGBLED(5, 6, 7)
led.green()

i2c = I2C(1, sda=Pin(10), scl=Pin(11))
vl53_1 = vl53l4cd.VL53L4CD(i2c, "VL53_1", VL53_XSHUNT_1, VL53_INT_1, VL53_ADDR_1, debug=debugging)
vl53_2 = vl53l4cd.VL53L4CD(i2c, "VL53_2", VL53_XSHUNT_2, VL53_INT_2, VL53_ADDR_2, debug=debugging)
vl53_3 = vl53l4cd.VL53L4CD(i2c, "VL53_3", VL53_XSHUNT_3, VL53_INT_3, VL53_ADDR_3, debug=debugging)
vl53_4 = vl53l4cd.VL53L4CD(i2c, "VL53_4", VL53_XSHUNT_4, VL53_INT_4, VL53_ADDR_4, debug=debugging)

irq1 = Pin(vl53_1.interrupt_pin, Pin.IN, Pin.PULL_DOWN)   # Normally low, high when pressed
esp32.wake_on_ext0(pin = irq1, level = esp32.WAKEUP_ANY_HIGH)
##TODO add other interrupts here

# Globale Variable, die den aktuellen Status des Events speichert
global event_in_progress
event_in_progress = False

global is_initial_irq
is_initial_irq = True

def event_handler(args):
    global event_in_progress

    print("Start Event")
    led.on()
    focus.on()
    time.sleep(0.01)
    shutter.on()
    time.sleep(0.5)
    focus.off()
    shutter.off()
    time.sleep(1.5)
    led.off()

    print("Camera Triggered")
    event_in_progress = False

def interrupt_handler(pin):
    print("IRQ on pin {}".format(pin))
    global event_in_progress
    
    if pin is vl53_1.interrupt_pin:
        vl53_1.clear_interrupt()
    if pin is vl53_2.interrupt_pin:
        vl53_2.clear_interrupt()
    elif pin is vl53_3.interrupt_pin:
        vl53_3.clear_interrupt()
    elif pin is vl53_4.interrupt_pin:
        vl53_4.clear_interrupt()

    global is_initial_irq
    if is_initial_irq:
        return
    if not event_in_progress:
        event_in_progress = True
        print("Scheduling event...")
        micropython.schedule(event_handler, None)

    print("IQR on pin {} ended!".format(pin))

# def get_temperature():
#     temps = []
#     for i in range(25):
#         reading = temperature_pin.read_u16() * TEMPERATURE_CONVERSION_FACTOR 
#         temperature = 27 - (reading - TEMPERATURE_OFFSET)/0.001721
#         # print("{}C".format(temperature))
#         temps.append(temperature)
#         time.sleep(0.05)

#     avg_temp = statistics.mean(temps)
#     print("Average temperature: {}C".format(avg_temp))
#     return avg_temp

# last_temperature = get_temperature()

sensor_array = [vl53_1, vl53_2, vl53_3, vl53_4]
print(i2c.scan())
for sensor in sensor_array:
    sensor.begin()

sensorcfg = sensorcfg.SensorCfg()
success = sensorcfg.load()
# success = False
if not success:
    sensorcfg.clear()
    print("No sensor data found. Calibrating...")
    for sensor in sensor_array:
        offset = sensor.calibrate_offset(100, 30)
        xtalk = sensor.calibrate_xtalk(100, 30)
        sensorcfg.set_sensor(sensor.name, offset, xtalk)
    sensorcfg.save()

for sensor in sensor_array:
    print("----------{}------------".format(sensor.name))
    sensor.start_temperature_update()
    sensor.set_xtalk(sensorcfg.get_sensor(sensor.name)["xtalk"])
    sensor.set_offset(sensorcfg.get_sensor(sensor.name)["offset"])
    threashold_mm = sensor.get_height_trigger_threashold(30, 5.5)
    sensor.sensor_init(vl53l4cd.Mode.LOW_POWER)
    sensor.set_signal_threshold(5000)
    print("Signal Threashold: {}".format(sensor.get_signal_threshold()))
    sensor.set_sigma_threshold(10)
    print("Sigma mm: {}".format(sensor.get_sigma_threshold()))
    sensor.set_measure_timings(TIME_TO_MEASURE, MEASURE_FREQUENCY)
    sensor.set_interrupt(threashold_mm, True)
    sensor.enable_interrupt(interrupt_handler)
    sensor.start_ranging()

time.sleep(0.1)
is_initial_irq = False

# def check_temperature(tmp):
#     global last_temperature
#     print("Check Temperature task running...")
#     current_temperature = get_temperature()
#     if abs(current_temperature - last_temperature) > 5:
#         print("Temperature changed by more than 5 degrees. Recalibrating...")
#         machine.reset()

# temperature_timer = machine.Timer(-1)
# temperature_timer.init(period=3600*1000, mode=machine.Timer.PERIODIC, callback=check_temperature)

for i in range(3):
    led.on()
    time.sleep(0.25)
    led.off()
    time.sleep(0.25)

while True:
    #idle()
    print ('Going to sleep')
    time.sleep(1)
    lightsleep(10000) #  10 seconds

    wakeReason = wake_reason()
    print ('Wake Reason =', wakeReason)
    print ('now get on with the rest of the program')

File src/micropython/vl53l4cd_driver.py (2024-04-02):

from constants import *
import uerrno
import struct

'''
uint32_t == 4 byte == >I
uint16_t == 2 byte == >H
uint8_t  == 1 byte == >B
struct.unpack(...)
'''

STATUS = {
    0: "None",
    1: "WARNING: Sigma is above the defined threshold",
    2: "WARNING: Signal is below the defined threshold",
    3: "ERROR: Measured distance is below detection threshold",
    4: "ERROR: Phase out of valid limit",
    5: "ERROR: Hardware fail",
    6: "WARNING: Phase valid but no wrap around check performed",
    7: "ERROR: Wrapped target, phase does not match",
    8: "ERROR: Processing fail",
    9: "ERROR: Crosstalk signal fail",
    10: "ERROR: Interrupt error",
    11: "ERROR: Merged target",
    12: "ERROR: Signal is too low"
}

class VL53L4CD_DRIVER:

    status_rtn = [ 255, 255, 255, 5, 2, 4, 1, 7, 3,
                0, 255, 255, 9, 13, 255, 255, 255, 255, 10, 6,
                255, 255, 11, 12 ]

    def __init__(self, i2c, debug=False):
        self.i2c_address = 41
        self._i2c = i2c
        self.debug = debug

    def get_system_status(self):
        self.debug_print("get_system_status")
        return self.read(FIRMWARE_SYSTEM_STATUS)[0]

    def get_identification_model_id(self):
        self.debug_print("get_identification_model_id")
        return self.read(IDENTIFICATION_MODEL_ID, 2)

    def set_i2c_address(self, newi2caddress):
        self.debug_print("set_i2c_address")
        self.write(I2C_SLAVE_DEVICE_ADDRESS, bytearray([newi2caddress]))
        old = self.i2c_address
        self.i2c_address = newi2caddress
        print("old address: {} | new address: {}".format(old, int.from_bytes(self.read(I2C_SLAVE_DEVICE_ADDRESS), "big")))

    def write_config(self, config):
        self.debug_print("write_config")
        self.write(SENSOR_CONFIG, config)

    def set_macrop_loop_bound(self, value):
        self.debug_print("set_macrop_loop_bound")
        self.write(VHV_CONFIG_TIMEOUT_MACROP_LOOP_BOUND, value)

    def clear_interrupt(self):
        self.debug_print("clear_interrupt")
        self.write(SYSTEM_INTERRUPT_CLEAR, b'\x01')

    def start_ranging(self):
        self.debug_print("start_ranging")
        inter_ms = self.get_inter_measurement()
        if (inter_ms == 0):
            self.debug_print("continuous mode")
            self.write(SYSTEM_START, b'\x21')
        else:
            self.debug_print("autonomous mode")
            self.write(SYSTEM_START, b'\x40')

    def start_ranging_single_shot(self):
        self.debug_print("start_ranging_single_shot")
        self.write(SYSTEM_START, b'\x10')

    def stop_ranging(self):
        self.debug_print("stop_ranging")
        self.write(SYSTEM_START, b'\x00')

    def is_data_ready(self) -> bool:
        self.debug_print("is_data_ready")
        int_pol = self.get_interrupt_polaritiy()
        tmp = self.read(GPIO_TIO_HV_STATUS)[0] & 0x01
        return True if tmp == int_pol else False
    
    def get_interrupt_polaritiy(self):
        self.debug_print("get_interrupt_polaritiy")
        int_pol = self.read(GPIO_HV_MUX_CTRL)[0] & 0x10
        int_pol = (int_pol >> 4) & 0x01
        return 0 if int_pol else 1
    
    def get_timing_budget(self):
        self.debug_print("get_timing_budget")
        """Ranging duration in milliseconds. Valid range is 10ms to 200ms."""
        osc_freq = struct.unpack(">H", self.read(0x0006, 2))[0]

        macro_period_us = 16 * (int(2304 * (0x40000000 / osc_freq)) >> 6)

        macrop_high = struct.unpack(">H", self.read(RANGE_CONFIG_A, 2))[0]

        ls_byte = (macrop_high & 0x00FF) << 4
        ms_byte = (macrop_high & 0xFF00) >> 8
        ms_byte = 0x04 - (ms_byte - 1) - 1

        timing_budget_ms = (((ls_byte + 1) * (macro_period_us >> 6)) - ((macro_period_us >> 6) >> 1)) >> 12
        if ms_byte < 12:
            timing_budget_ms >>= ms_byte
        if self.get_inter_measurement() == 0:
            # mode continuous
            timing_budget_ms += 2500
        else:
            # mode autonomous
            timing_budget_ms *= 2
            timing_budget_ms += 4300

        return int(timing_budget_ms / 1000)

    def set_timing_budget(self, timing_budget_ms):
        self.debug_print("set_timing_budget")
        if not 10 <= timing_budget_ms <= 200:
            raise ValueError("Timing budget range duration must be 10ms to 200ms.")

        inter_meas = self.get_inter_measurement()
        if inter_meas != 0 and timing_budget_ms > inter_meas:
            raise ValueError(
                "Timing budget can not be greater than inter-measurement period ({})".format(
                    inter_meas
                )
            )

        osc_freq = struct.unpack(">H", self.read(0x0006, 2))[0]
        if osc_freq == 0:
            raise RuntimeError("Osc frequency is 0.")

        timing_budget_us = timing_budget_ms * 1000
        macro_period_us = int(2304 * (0x40000000 / osc_freq)) >> 6

        if inter_meas == 0:
            # continuous mode
            timing_budget_us -= 2500
        else:
            # autonomous mode
            timing_budget_us -= 4300
            timing_budget_us //= 2

        # VL53L4CD_RANGE_CONFIG_A register
        ms_byte = 0
        timing_budget_us <<= 12
        tmp = macro_period_us * 16
        ls_byte = int(((timing_budget_us + ((tmp >> 6) >> 1)) / (tmp >> 6)) - 1)
        while ls_byte & 0xFFFFFF00 > 0:
            ls_byte >>= 1
            ms_byte += 1
        ms_byte = (ms_byte << 8) + (ls_byte & 0xFF)
        self.write(RANGE_CONFIG_A, struct.pack(">H", ms_byte))

        # VL53L4CD_RANGE_CONFIG_B register
        ms_byte = 0
        tmp = macro_period_us * 12
        ls_byte = int(((timing_budget_us + ((tmp >> 6) >> 1)) / (tmp >> 6)) - 1)
        while ls_byte & 0xFFFFFF00 > 0:
            ls_byte >>= 1
            ms_byte += 1
        ms_byte = (ms_byte << 8) + (ls_byte & 0xFF)
        self.write(RANGE_CONFIG_B, struct.pack(">H", ms_byte))

    def get_inter_measurement(self):
        """
        Inter-measurement period in milliseconds. Valid range is timing_budget to
        5000ms, or 0 to disable.
        """
        self.debug_print("get_inter_measurement")
        reg_val = struct.unpack(">I", self.read(INTERMEASUREMENT_MS, 4))[0]
        clock_pll = struct.unpack(">H", self.read(RESULT_OSC_CALIBRATE_VAL, 2))[0]
        clock_pll &= 0x3FF
        clock_pll = int(1.065 * clock_pll)
        if clock_pll is 0: return 0
        return int(reg_val / clock_pll)

    def set_inter_measurement(self, inter_measurement_ms):
        self.debug_print("set_inter_measurement")
        timing_bud = self.get_timing_budget()
        if inter_measurement_ms != 0 and inter_measurement_ms < timing_bud:
            raise ValueError("Inter-measurement period can not be less than timing budget ({})".format(timing_bud))
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

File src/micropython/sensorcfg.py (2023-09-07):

import json
from micropython import const

FILENAME = const("sensorcfg.json")
READ = const("r")
WRITE = const("w")

def save_sensor_data(sensordata):
    try:
      with open(FILENAME, WRITE) as f:
          json.dump(sensordata, f)
      print("Sensor data saved to file.")
    except:
      print("Error saving sensor data to file.")

def get_sensor_data():
    try:
      with open(FILENAME, READ) as f:
          return json.load(f)
    except:
      print("Error loading sensor data from file.")
    return None
    
class SensorCfg:
   sensorcfgs = []

   def set_sensor(self, name, offset, xtalk):
      self.sensorcfgs.append({"name": name, "offset": offset, "xtalk": xtalk})

   def get_sensor(self, name):
      for sensor in self.sensorcfgs:
         if sensor["name"] == name:
            return sensor
      return None

   def save(self):
      print("Saving sensor data: {}".format(self.sensorcfgs))
      save_sensor_data(self.sensorcfgs)

   def load(self):
      self.sensorcfgs = get_sensor_data()
      print("Loaded sensor data: {}".format(self.sensorcfgs))
      if self.sensorcfgs is None:
         self.sensorcfgs = []
         return False
      return True
   
   def clear(self):
      self.sensorcfgs = []
      save_sensor_data(self.sensorcfgs)

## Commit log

2023-07-01 Added initial PCB project
    [KiBot-CICD-Template.kicad_pcb, KiBot-CICD-Template.kicad_sch, rep-trap-pcb.kicad_pcb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]
2023-07-01 Added prototyping code for validating multiple sensor usage
2023-07-05 Added first components and size check
    [CUI_DEVICES_SJ-3541AS-SMT-TR-67.step, USB4105-GF-A.step, VL53L4CDV0DH_1.stp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]
2023-07-13 Added pcb design for first prototype
    [1042P.stp, ABLS-12.000MHZ-B4-T.stp, ABMM2-12.000MHZ-E2-T.stp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]
2023-07-13 Added Logo + Revision + generated Bom
    [rep-trap-pcb.kicad_pcb]
2023-07-14 Refactored details component namings + bom excludings
    [main.kicad_sch, mcu.kicad_sch, psu_charging.kicad_sch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]
2023-07-14 Moved via out of the pad
    [rep-trap-pcb.kicad_pcb]
2023-07-14 Applied the vias of the RP2040
    [rep-trap-pcb.kicad_pcb]
2023-07-26 Removed debounce IC and replaced with default on off switch
    [STP_450405020524 (rev1).stp, main.kicad_sch, rep-trap-pcb.kicad_pcb]
2023-08-02 Applied ERC issue changes + DRC issues fix
    [mcu.kicad_sch, psu_charging.kicad_sch, rep-trap-pcb.kicad_pcb]
2023-08-07 Added more options to the kibot config for bom generation, 3d file etc.
2023-08-07 Added missing list to gerber generation
2023-08-08 Added basic kibot config
    [rep-trap-pcb.kicad_pcb]
2023-08-16 Added notes and ToDos to be worked on for REV.02
    [main.kicad_sch, psu_charging.kicad_sch, rep-trap-pcb.kicad_pcb]
2023-08-16 Changed code to calibrate the sensor on boot and trigger only once after detection
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2023-08-25 Added housing 3D file done with sketcher
    [housing.stl, housing2.stl, rep-trap-pcb.kicad_pcb]
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2023-09-05 Added In1.Cu and In2.Cu to the gerber export
2023-09-07 Current Firmware state incl. manufacturing calibration, height calibration threashold and sleep mode (bad)
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2023-09-28 Run kibot action only on changes in pcb folder or tags
2024-01-07 refactored components and layout
    [12401861.stp, CUI_DEVICES_SJ-3541AS-SMT-TR-67.step, DRV5032DULPGM.stp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]
2024-02-05 re-organise components + added housing data
    [APHF1608.IGS, APHF1608.STEP, APHF1608SEEQBDZGKC_KNB.step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]
2024-02-05 Added upload script to upload all micropython files + changed values to trigger much faster (more power consumption)
2024-02-07 Replaced RP2040 with ESP32 + Schematics + Layouting
    [1N5819HW-7-F.stp, LESD5D5.0CT1G.stp, main.kicad_sch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]
2024-02-09 Changed Battery silk to plus and minus + added 18650 battery STEP file to the battery holder
    [18650.step, rep-trap-pcb.kicad_pcb]
2024-02-10 Connected PCB GND with enclosure mounting screws
    [main.kicad_sch, rep-trap-pcb.kicad_pcb]
2024-02-12 Added dimension scales
    [rep-trap-pcb.kicad_pcb]
2024-02-12 Renamed tracks to fix ERC warnings
    [rep-trap-pcb.kicad_pcb, tof-array.kicad_sch]
2024-02-12 Modified components to fix ERC issues
    [rep-trap-pcb.kicad_pcb]
2024-02-12 Fix thermal relieve gap
    [rep-trap-pcb.kicad_pcb]
2024-02-12 Fix DRC issue TH vs. SMD
    [rep-trap-pcb.kicad_pcb]
2024-02-12 Fixed wrong ESP32-S3 footprint
    [mcu.kicad_sch, rep-trap-pcb.kicad_pcb]
2024-02-12 Added missing 3D Step file for ESP32-S3
    [ESP32-S3-WROOM-1-N8.STEP, rep-trap-pcb.kicad_pcb]
2024-02-12 Try to ignore DRC issues
    [rep-trap-pcb.kicad_pcb]
2024-02-12 Fixed ESP32-S3 footprint and symbol issues
    [ESP32-S3-WROOM-1-N8.STEP, mcu.kicad_sch, rep-trap-pcb.kicad_pcb]
2024-02-12 Removed DNP components from BOM
    [main.kicad_sch, rep-trap-pcb.kicad_pcb]
2024-02-16 Removed diode from VBUS to 5V+ and removed 5V+ because it is not needed
    [psu_charging.kicad_sch, rep-trap-pcb.kicad_pcb]
2024-02-16 Removed capacitor from one of the mountingholes
    [main.kicad_sch, rep-trap-pcb.kicad_pcb]
2024-02-19 Changed net names to match functionallity of active low
    [main.kicad_sch, mcu.kicad_sch, psu_charging.kicad_sch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]
2024-03-07 Moved magnet switch to the other side
    [mcu.kicad_sch, rep-trap-pcb.kicad_pcb]
2024-03-07 Added new housing + magent switch
    [Schalter2.stl, Schalterhalter2.stl]
2024-03-07 Updated footprints try to fix DRC
    [main.kicad_sch, mcu.kicad_sch, psu_charging.kicad_sch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]
2024-03-15 Fixed usage of strapping pins
    [mcu.kicad_sch, rep-trap-pcb.kicad_pcb]
2024-03-18 Swapped 100-Ohms with 47-Ohms for the optocoupler
    [main.kicad_sch]
2024-03-18 Mark oull-down resistor for EN pin as DNP
    [psu_charging.kicad_sch]
2024-03-18 Updated PCB with changed values
    [rep-trap-pcb.kicad_pcb]
2024-03-20 Added Enclosure changes and removed old enclosure data
    [240319_Gehaeuse.stp, 240319_Schalter.stl, 240319_Schalterhalter.stl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]
2024-04-02 Added print status function to the driver t oget a readable status
2024-04-02 Applied changes for the new hardware revision + rgbled + dedicated calibrator function
2024-04-05 Refactored toit implementation
    ISSUE: measurment of the sensors return 0 most of the time
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2024-04-08 Added BLE service to trigger the camera from remote and re-calibrate the sensor remotely
2024-04-08 Added stl for the glas and step file for the latch
    [glass.stl]
2024-04-08 Added changes to pcb + added production files from latest generation
    [rep-trap-pcb.kicad_pcb]
2024-04-09 Added sensor manager and refactored code to fix issues the gpio containers
2024-04-12 Changed interrupt polarity to match HIGH instead of LOW + add correct way to finish BLE service
    Note: interrupt seems only to work with sensor 4
2024-04-12 Reversed the interrupt from high active back to low active
2024-04-14 Moved hardcoded RGB LED gpio declaration into the rgb-led class
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2024-04-15 Added BLE device state + fixed crashes + removed unused code
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2024-04-17 Added calibration holder 3d print file
    [calibration-station.3mf]
2024-04-22 Refactored code and save current state of development
2024-04-23 Add changed pcb files
    [PJ-3255A.stp, psu_charging.kicad_sch, rep-trap-pcb.kicad_pcb]
2024-04-23 Run kibot action only on tags with pcb*
2024-04-28 Finally seem to fixed the sensor issues
2024-04-28 Fix pin extract
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2024-05-01 Disabled sensor 2 and added original low power code t oset inter-measurment-ms and timing-busget
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2024-05-07 Fix decoupling cap swap + refactored and cleaned the layout a bit
    [rep-trap-pcb.kicad_pcb]
2024-05-07 Moved vias further away from the sensors + added silk on bottom side for debug connector
    [rep-trap-pcb.kicad_pcb]
2024-05-07 Removed unnecessary 10ms sleep after each i2c write
2024-05-07 Set I2C ADDR for the VL53L4CD Sensor further appart due to address collisions
2024-05-07 Set I2C frequency to 300.000 insteat of 400k to avoid wierd spikes on SDA + removed 1s sleep after each sensor init
2024-05-07 Removed handling of 0mm until we found out why this happens
2024-05-07 Added Testpoints on bottom side
    [main.kicad_sch, mcu.kicad_sch, psu_charging.kicad_sch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]
2024-05-07 Updated footprint for DRC errors
    [rep-trap-pcb.kicad_pcb]
2024-05-08 Try to fix warnings by actually using the exclusions from KiCad with KiBot
2024-05-08 Ignore Warning 58 (Footprint does not match copy in library)
2024-05-08 Update to use KiCad8
    [main.kicad_sch, mcu.kicad_sch, psu_charging.kicad_sch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]
2024-05-08 micropython: changed get-distance to get-result and beautify prints
2024-05-13 Add 3ms sleep after i2c write to fix the issue with the sensors
2024-05-13 Reduced trigger time by 60ms+ by not spawning and pass rgb-led
2024-05-17 Refactored code +fixed USB-C unplug device reset + fix blink after calibration finished
2024-05-17 Getting back to old values incl. 400k i2c speed
2024-05-28 Fix calibration of xtalk (still seems to breack the sensor)
2024-05-28 Fixed to only run BLE if the device was hard reset and USB-C is connected
2024-11-06 updated housing files
    [240530needles.stl, rep-trap-gehaeuse_240506.stp]
2024-11-06 PCB update
    [main.kicad_sch, psu_charging.kicad_sch, rep-trap-pcb.kicad_pcb]
